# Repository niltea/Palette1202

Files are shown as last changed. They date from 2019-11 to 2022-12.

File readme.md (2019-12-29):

# Nilgiri12-02EC

English follows Japanese.

--------------------

Nilgiri12-02ECは、イラストレーターのための左手デバイスです。  
[Clip studio Paint](https://www.clipstudio.net) や、 [Adobe Photoshop](https://www.adobe.com/jp/products/photoshop.html)を使用した描画を快適に行うため設計されています。  
各種ショートカットを使用するためのキーを備えていることはもちろん、  
つまみを操作することで、ブラシサイズの変更やキャンバスの拡大・縮小等を快適に行うことができます。

コンパクトなサイズに設計されているため、持ち運んでの使用にも便利なだけでなく、  
据え置き環境で大型の液晶タブレットと一緒に使っても邪魔になりません。

また、オプションの電池キットを追加することで[BLE Micro Pro](https://yushakobo.jp/shop/ble-micro-pro/)にも対応するため、  
持ち運びの際でもケーブルが煩わしくありません。

Windows/Mac・Clip Studio / Photoshopの切替を行う事ができるため、  
PC・Macはもちろん、iPadでも同じ操作感で描画することができます。

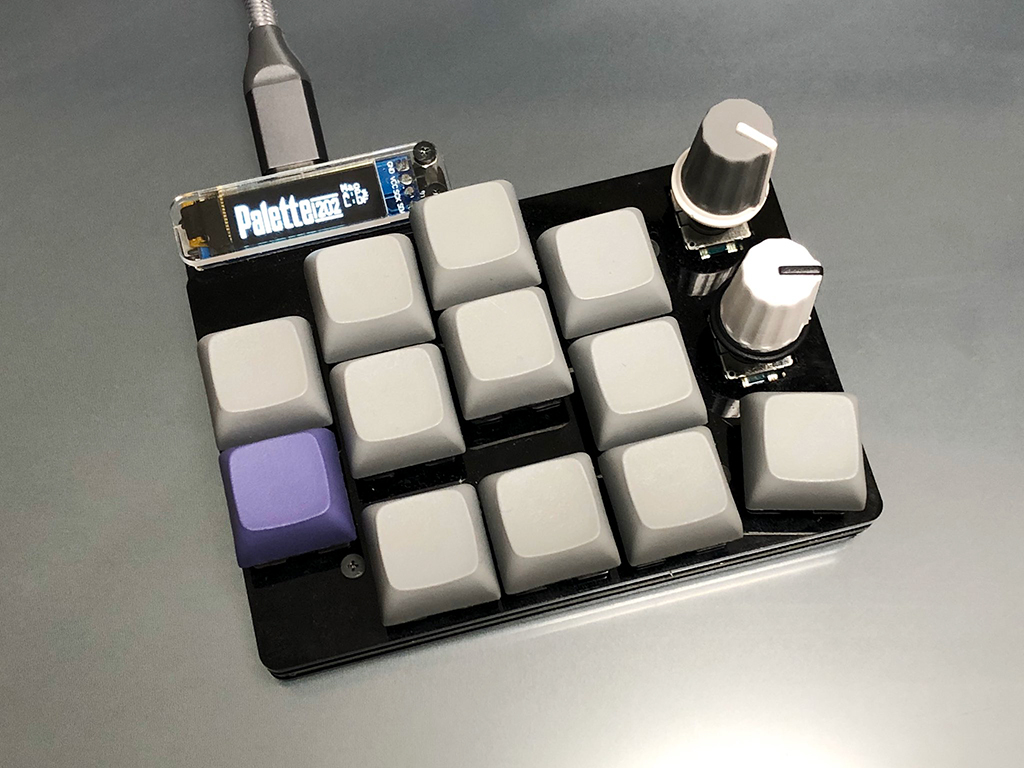
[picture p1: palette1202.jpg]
Palette1202


--------------------

Nilgiri12-02EC is a lefthand-devece for illustrators. 
Designed for comfotablly drawing on [Clip studio Paint](https://www.clipstudio.net) / [Adobe Photoshop](https://www.adobe.com/jp/products/photoshop.html).

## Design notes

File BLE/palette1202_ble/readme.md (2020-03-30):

# Palette1202-ble

Palette1202

A left hand device with rotary encoder, for artists.
firmware for BLE Micro Pro.

* Keyboard Maintainer: [niltea](https://github.com/niltea)
* Hardware Supported: Palette1202
* Hardware Availability: [Pixiv Booth](https://niltea.booth.pm/)
* [PCB & Case](https://github.com/niltea/Palette1202)

Make example for this keyboard (after setting up your build environment):

- default

		make palette1202-ble:default:nrfutil
        
- key check (for after build)

		make palette1202-ble:key-check:nrfutil

See the [build environment setup](https://docs.qmk.fm/#/getting_started_build_tools) and the [make instructions](https://docs.qmk.fm/#/getting_started_make_guide) for more information. Brand new to QMK? Start with our [Complete Newbs Guide](https://docs.qmk.fm/#/newbs).

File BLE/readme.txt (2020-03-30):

# firmware for Palette1202 BLE

BLE Micro Pro用のPalette1202ファームウェアです。

## フォルダ構成

### palette1202-ble/

QMK Firmware用のファイル一式です。
keyboards以下にコピーし、下記コマンドで書き込みを行ってください。  
```make palette1202-ble:default:nrfutil```

### config/

config / keymapファイルです。
ファームウェア書き込み後、BLE Micro Proをマスストレージデバイスとして接続し、転送してください。

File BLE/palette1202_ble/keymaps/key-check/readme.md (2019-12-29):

# The test-purpose keymap for niltea
組み立て後のテスト用keymapです。

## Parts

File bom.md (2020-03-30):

# Bills of materials

## Options

Option 1: direct mount ATmega32U4
Option 2: Use Pro Micro(uses 12pin Conthrough)
Option 3: Use BLE Micro Pro(uses 13pin Conthrough)

## List

| part ID | Description | Count | Remarks | Op1 | Op2 | Op3 |  color  |
|---|---|---| --- | :-: | :-: | :-: | :-----: |
| BT1-2 | Battery Holder(\*) | 2 | Keystone 504  | | |  v  | |
| C1 | Tantalum 1206 / 3216M | 1 | 10uF |  v  | | | |
| C2-3 | C 0603 / 1608M | 2 | 1uF |  v  | | | puprple |
| C4-5 | C 0603 / 1608M | 2 | 0.1uF |  v  | | |  green  |
| C6-7 | C 0603 / 1608M | 2 | 22pF |  v  | | | orange  |
| C10 | Tantalum 1206 / 3216M | 1 | 100uF | | |  v  | |
| U1 | Controller | 1 | ATmega32U4-AU |  v  | | | |
| U1 | Pro Micro | 1 | normal / BLE  | |  v  |  v  | |
| D1-14 | Diode | 14 | 1N4148W |  v  |  v  |  v  | |
| D20 | Shotkey Diode | 1 | MBR120 |  v  | | | |
| D31-32  | Shotkey Diode(\*) | 2 | MBR120 | | |  v  |
| R1-2 | R 0603 / 1608M | 2 | 5.1kΩ |  v  | | |
| R3-4 | R 0603 / 1608M | 2 | 22Ω |  v  | | |
| R5 | R 0603 / 1608M | 1 | 10kΩ |  v  | | |
| F1 | PTC 1206 / 3216M | 1 | 500mA |  v  | | |
| Y1 | Xtal 3225M 4pin | 1 | 16MHz |  v  | | |
| SW1-12  | Kailh Hotswap | 12 | MX / Choc |  v  |  v  |  v  |
| SW20 | Tactile Switch | 1 | 6mm x 3.5mm |  v  |  v  |  v  |
| SW21 | Slide Switch | 1 | SMD SPDT | | |  v  |
| EC1-2 | Rotary encoder | 2 | EC11E1834403  |  v  |  v  |  v  |
| knob | knob for encoder | 2 | 20mm max |  v  |  v  |  v  |
| J1 | USB Type-C | 1 | 16pin |  v  | | |
| J2 | USB Type-B Micro | 1 | micro,SMD |  v  | | |
| J3 | ISP Pin Header | 1 | 2x3pin | | | |
| J\* | Conthrough(\*) | 2 | 12 / 13pin | |  v  |  v  |
| OLED | | 1 | Optional | | | |

| vis     | M2 3mm                | 12    |               |  v  |  v  |  v  |
| spacer  | hirosugi M2x7mm       | 6     |               |  v  |  v  |  v  |

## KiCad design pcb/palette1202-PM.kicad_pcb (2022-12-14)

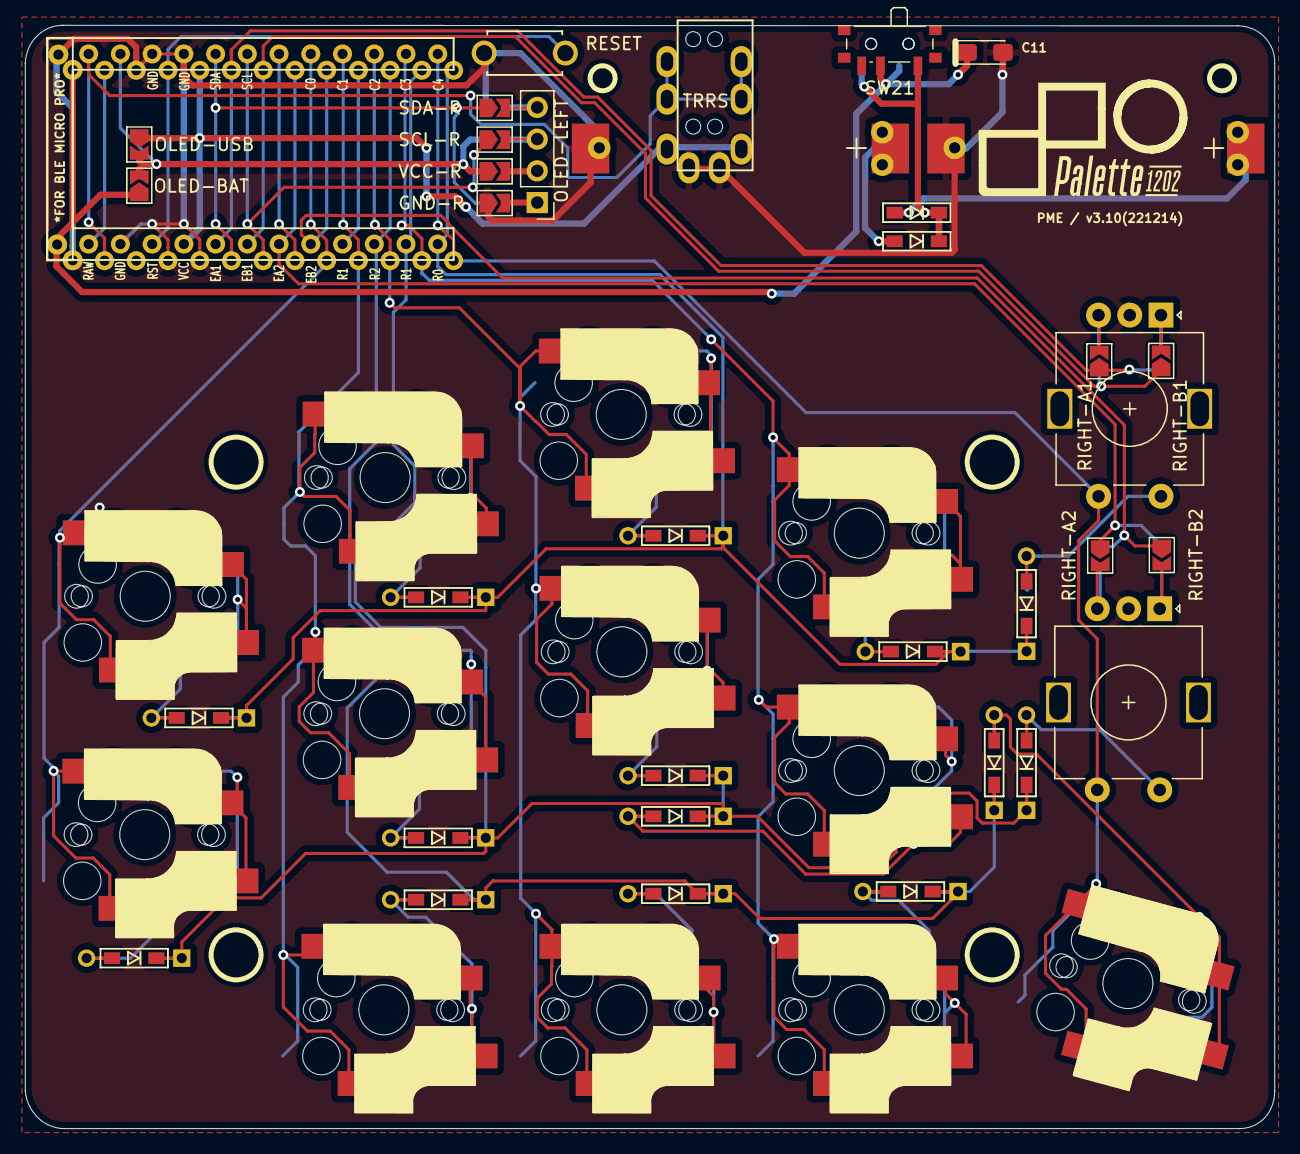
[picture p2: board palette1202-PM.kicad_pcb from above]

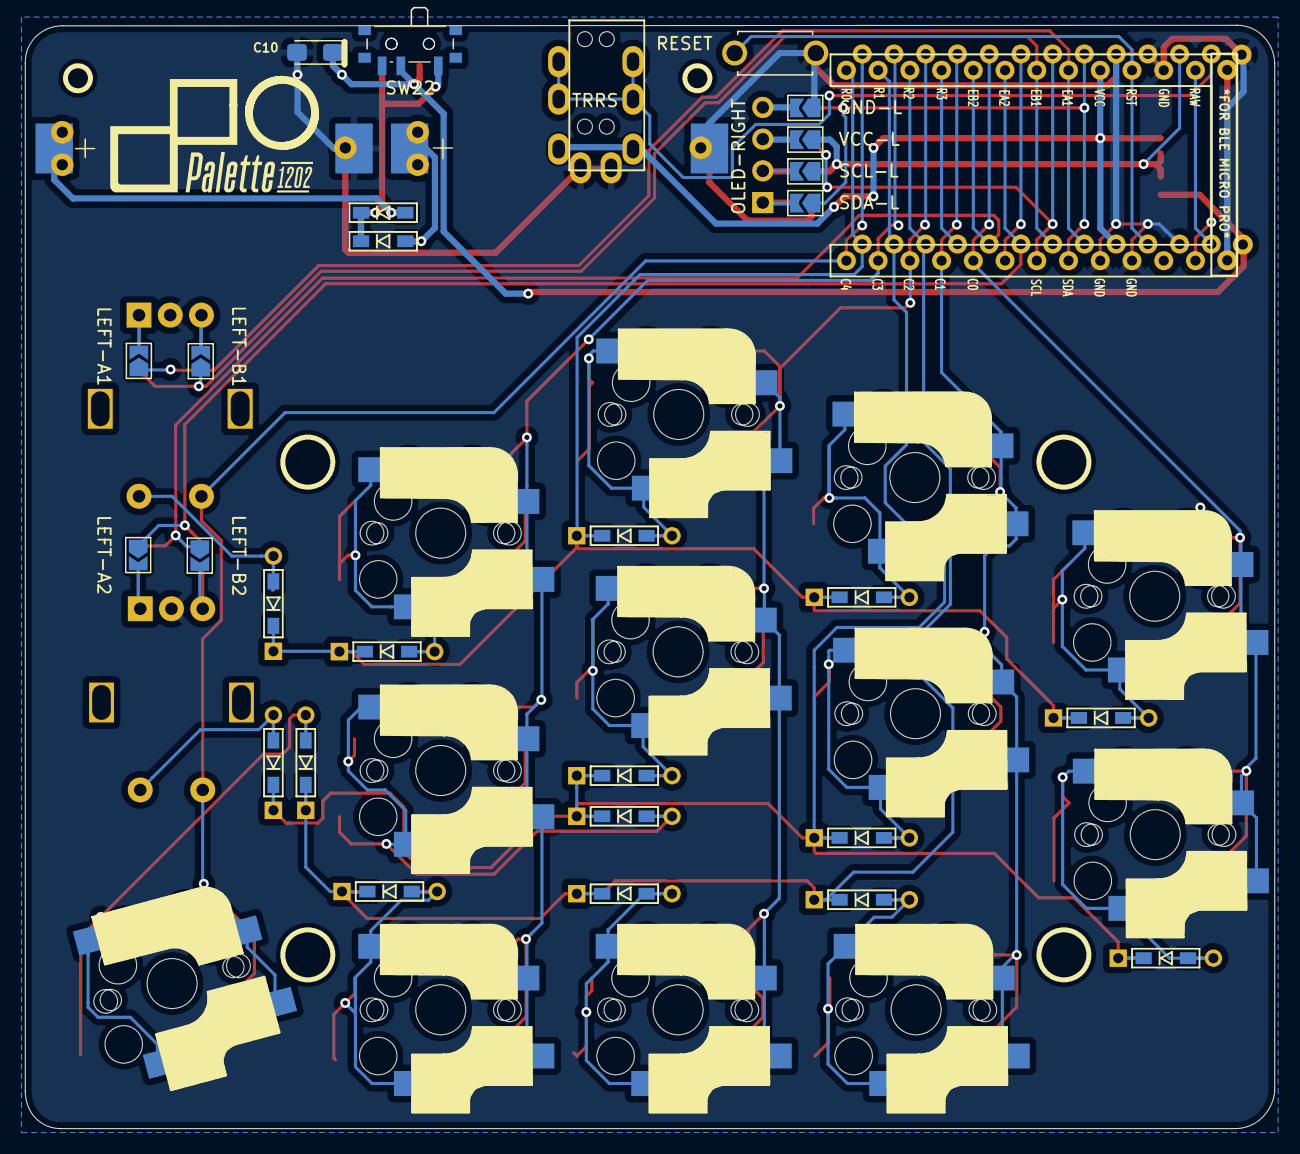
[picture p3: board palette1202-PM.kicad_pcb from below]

Board: 2 copper layers, 100.0 x 88.3 mm, 68 parts (26 on the bottom side), 45 nets.

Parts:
BT1, BT2: 3V; HU1632
C10, C11: 100u; CP_EIA-3216-10_Kemet-I_Pad1.58x1.35mm_HandSolder
D1, D2, D3, D4, D5, D6, D7, D8, D9, D10, D11, D12, D13, D14: 1N4148W; D3_TH_SMD
D30, D31: MBR120; D3_SMD
EC1, EC2: EC11E18244A5; RotaryEncoder_Alps_EC11E-Switch_Vertical_H20mm
GND-L: LEFT-GND; SolderJumper-2_P1.3mm_Open_TrianglePad1.0x1.5mm
GND-R: RIGHT-GND; SolderJumper-2_P1.3mm_Open_TrianglePad1.0x1.5mm
H1, H3: MountingHole; M2_vis
H5, H6, H7, H8: MountingHole; M2_spacer
J1: MJ-4PP-9
J10, J20: BAT+; Hole 0.8mm
J11, J21: BAT-; Hole 0.8mm
JP100: LEFT-A1; SolderJumper-2_P1.3mm_Open_TrianglePad1.0x1.5mm
JP101: LEFT-B1; SolderJumper-2_P1.3mm_Open_TrianglePad1.0x1.5mm
JP110: RIGHT-B1; SolderJumper-2_P1.3mm_Open_TrianglePad1.0x1.5mm
JP111: RIGHT-A1; SolderJumper-2_P1.3mm_Open_TrianglePad1.0x1.5mm
JP120: LEFT-A2; SolderJumper-2_P1.3mm_Open_TrianglePad1.0x1.5mm
JP121: LEFT-B2; SolderJumper-2_P1.3mm_Open_TrianglePad1.0x1.5mm
JP130: RIGHT-B2; SolderJumper-2_P1.3mm_Open_TrianglePad1.0x1.5mm
JP131: RIGHT-A2; SolderJumper-2_P1.3mm_Open_TrianglePad1.0x1.5mm
JP220: OLED-USB; SolderJumper-2_P1.3mm_Open_TrianglePad1.0x1.5mm
JP221: OLED-BAT; SolderJumper-2_P1.3mm_Open_TrianglePad1.0x1.5mm
OLED-LEFT: OLED; PinHeader_1x04_P2.54mm_Vertical
SCL-L: LEFT-SCL; SolderJumper-2_P1.3mm_Open_TrianglePad1.0x1.5mm
SCL-R: RIGHT-SCL; SolderJumper-2_P1.3mm_Open_TrianglePad1.0x1.5mm
SDA-L: LEFT-SDA; SolderJumper-2_P1.3mm_Open_TrianglePad1.0x1.5mm
SDA-R: RIGHT-SDA; SolderJumper-2_P1.3mm_Open_TrianglePad1.0x1.5mm
SW1, SW2, SW3, SW4, SW5, SW6, SW7, SW8, SW9, SW10, SW11, SW12: SW_PUSH; CherryMX_Choc_Hotswap
SW20: SW_RESET; ResetSW_1side
SW21, SW22: PWR; SW_SPDT_PCM12
U2: ProMicro; ProMicro_v2
VCC-L: LEFT-VCC; SolderJumper-2_P1.3mm_Open_TrianglePad1.0x1.5mm
VCC-R: RIGHT-VCC; SolderJumper-2_P1.3mm_Open_TrianglePad1.0x1.5mm

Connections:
Col0: SW1.1, SW2.1, U2.8 (5/C6)
Col1: SW3.1, SW4.1, SW5.1, U2.9 (6/D7)
Col2: SW6.1, SW7.1, SW8.1, U2.10 (7/E6)
Col3: SW9.1, SW10.1, SW11.1, U2.11 (8/B4)
Col4: EC1.S1, EC2.S1, SW12.1, U2.12 (9/B5)
DATA: J1.B, J1.C, U2.1 (TX0/D3)
GND: BT1.2 (-), BT2.2 (-), C10.2, C11.2, EC1.C, EC2.C, GND-L.1, GND-R.1, J1.A, J11.1, J21.1, SW20.1, U2.3 (GND), U2.4 (GND), U2.23 (GND)
LEFT: JP220.2 (B), JP221.2 (B), U2.2 (RX1/D2), VCC-L.1, VCC-R.1
unnamed: BT1.1 (+), D31.2 (A)
unnamed: BT2.1 (+), D30.2 (A)
unnamed: D1.2 (A), SW1.2
unnamed: D2.2 (A), SW2.2
unnamed: D3.2 (A), SW3.2
unnamed: D4.2 (A), SW4.2
unnamed: D5.2 (A), SW5.2
unnamed: D6.2 (A), SW6.2
unnamed: D7.2 (A), SW7.2
unnamed: D8.2 (A), SW8.2
unnamed: D9.2 (A), SW9.2
unnamed: D10.2 (A), SW10.2
unnamed: D11.2 (A), SW11.2
unnamed: D12.2 (A), SW12.2
unnamed: D13.2 (A), EC1.S2
unnamed: D14.2 (A), EC2.S2
unnamed: D30.1 (K), D31.1 (K), SW21.1 (A), SW22.1 (A)
unnamed: EC1.A, JP100.2, JP110.2
unnamed: EC1.B, JP101.2, JP111.2
unnamed: EC2.A, JP120.2, JP130.2
unnamed: EC2.B, JP121.2, JP131.2
unnamed: GND-R.2, OLED-LEFT.1, SDA-L.2
unnamed: OLED-LEFT.2, SCL-L.2, VCC-R.2
unnamed: OLED-LEFT.3, SCL-R.2, VCC-L.2
unnamed: GND-L.2, OLED-LEFT.4, SDA-R.2
RA1: JP100.1, JP111.1, U2.20 (F4/A3)
RA2: JP120.1, JP131.1, U2.18 (F6/A1)
RB1: JP101.1, JP110.1, U2.19 (F5/A2)
RB2: JP121.1, JP130.1, U2.17 (F7/A0)
RESET: SW20.2, U2.22 (RST)
Row0: D1.1 (K), D3.1 (K), D6.1 (K), D9.1 (K), D13.1 (K), U2.13 (B6/10)
Row1: D2.1 (K), D4.1 (K), D7.1 (K), D10.1 (K), D14.1 (K), U2.14 (B2/16)
Row2: D5.1 (K), D8.1 (K), D11.1 (K), D12.1 (K), U2.15 (B3/14)
SCL: SCL-L.1, SCL-R.1, U2.6 (3/D0/SCL)
SDA: SDA-L.1, SDA-R.1, U2.5 (2/D1/SDA)
VCC: J1.D, JP220.1 (A), U2.21 (VCC)
Vbat: C10.1, C11.1, J10.1, J20.1, JP221.1 (A), SW21.2 (B), SW22.2 (B)

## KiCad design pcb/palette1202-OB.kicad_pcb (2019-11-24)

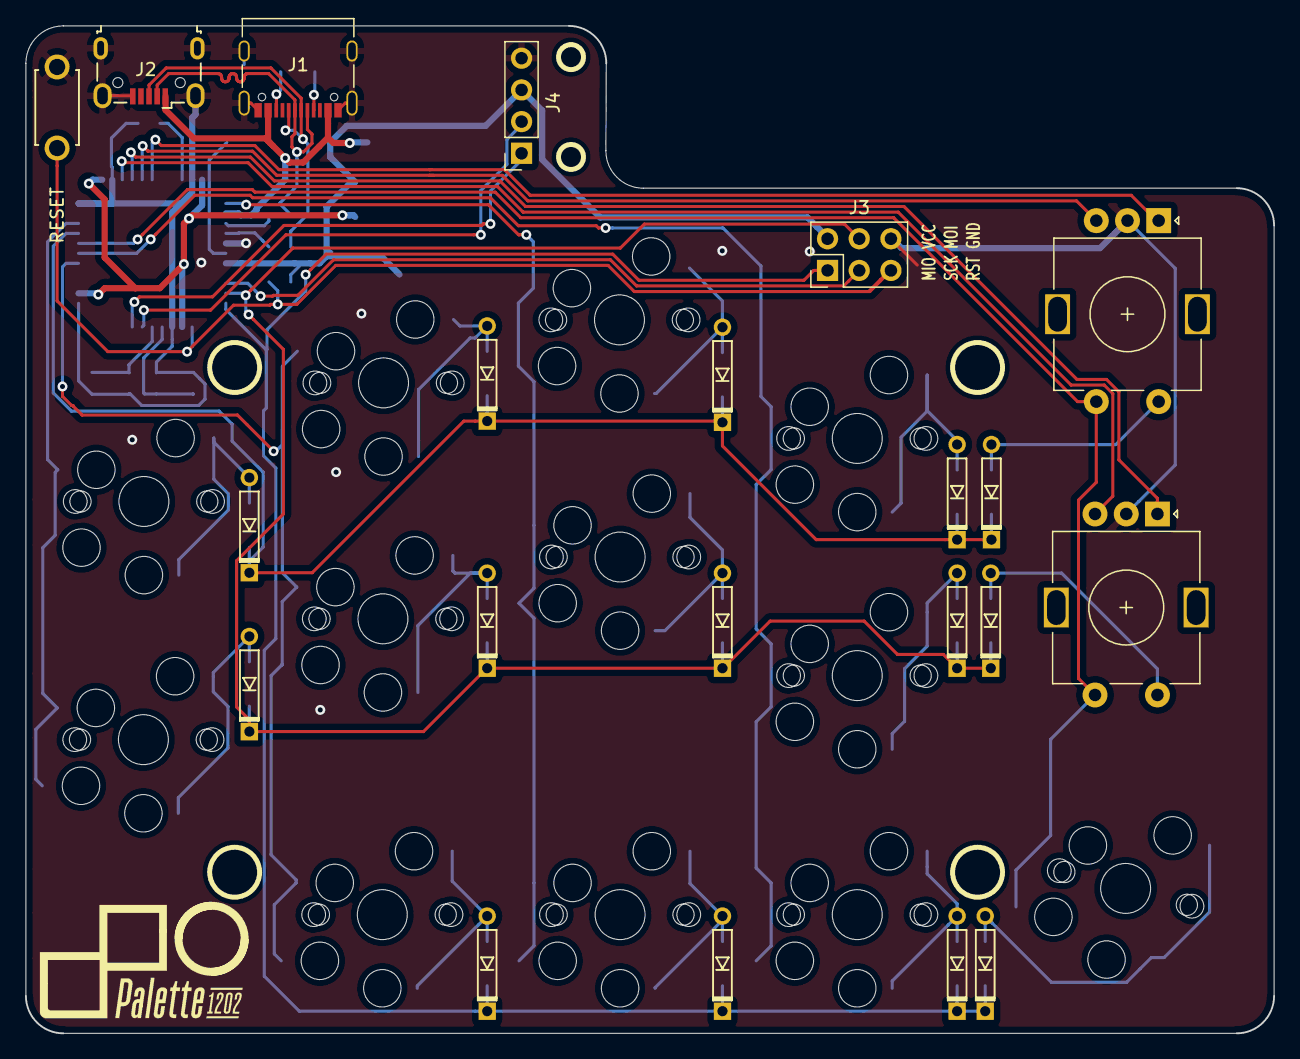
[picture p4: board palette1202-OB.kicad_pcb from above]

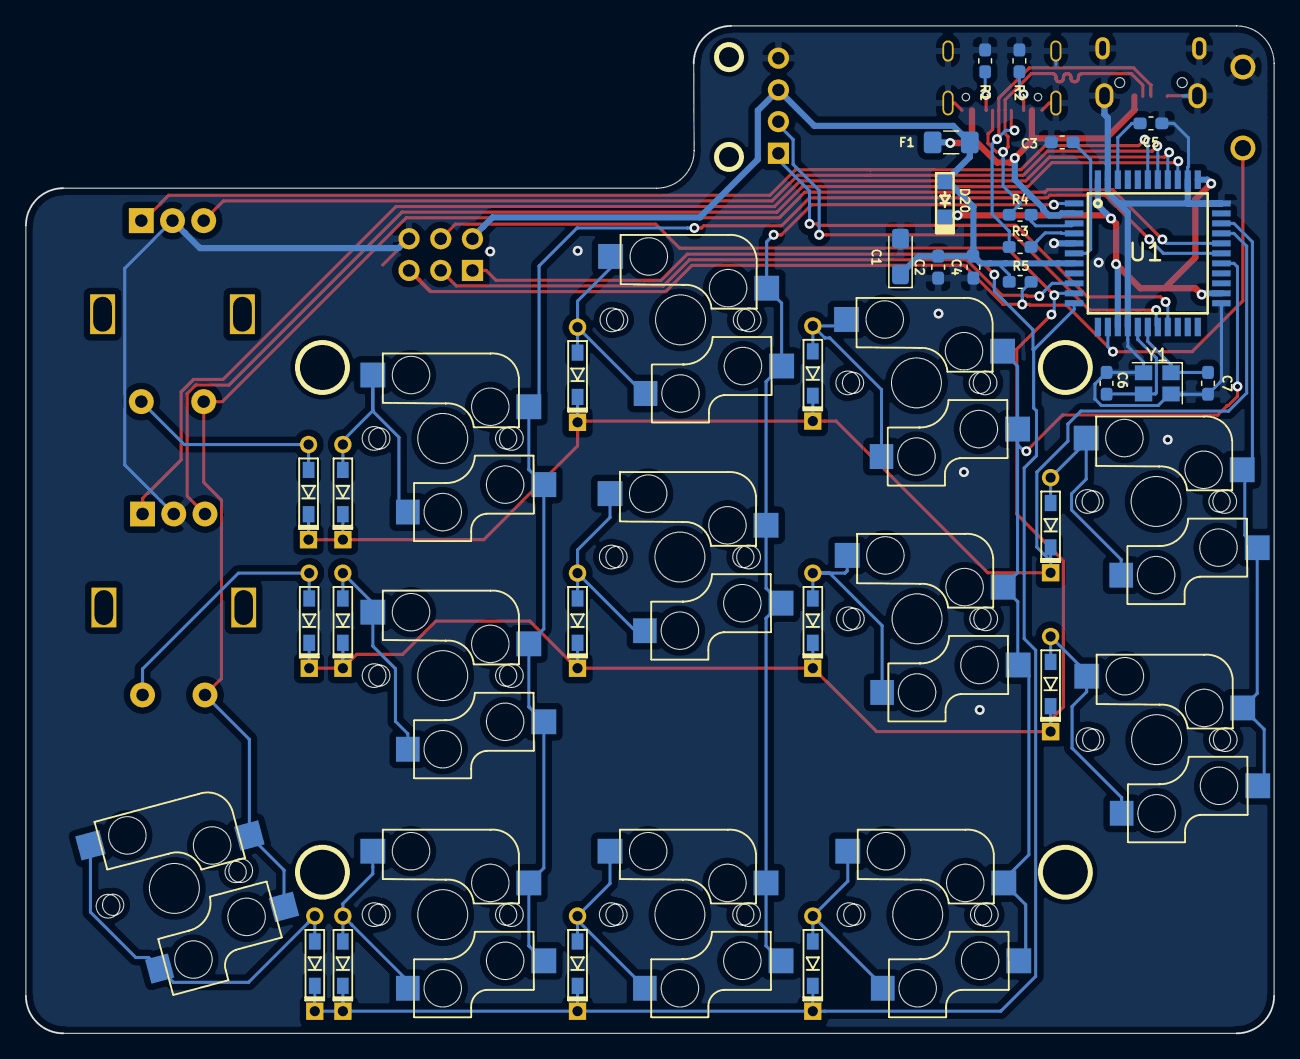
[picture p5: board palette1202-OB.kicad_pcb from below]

Board: 2 copper layers, 100.0 x 80.7 mm, 55 parts (30 on the bottom side), 44 nets.

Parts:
C1: 10u; CP_EIA-3216-10_Kemet-I_Pad1.58x1.35mm_HandSolder
C2, C3: 1u; C_0603_1608Metric_Pad1.05x0.95mm_HandSolder
C4, C5: 0.1u; C_0603_1608Metric_Pad1.05x0.95mm_HandSolder
C6, C7: 22p; C_0603_1608Metric_Pad1.05x0.95mm_HandSolder
D1, D2, D3, D4, D5, D6, D7, D8, D9, D10, D11, D12, D13, D14: 1N4148W; D3_TH_SMD
D20: MBR120; D_SOD123F
EC1, EC2: EC11E18244A5; RotaryEncoder_Alps_EC11E-Switch_Vertical_H20mm
F1: 500mA; Fuse_1206_3216Metric_Pad1.42x1.75mm_HandSolder
H1, H3: MountingHole; M2_vis
H5, H6, H7, H8: MountingHole; M2_spacer
J1: USB-C; USB_C_Receptacle_Palconn_UTC16-G
J2: USB_B_Micro; USB_Micro-B_Wuerth_629105150521
J3: ISP; PinHeader_2x03_P2.54mm_Vertical
J4: OLED; PinSocket_1x04_P2.54mm_Vertical
R1, R2: 5.1k; R_0603_1608Metric_Pad1.05x0.95mm_HandSolder
R3, R4: 22; R_0603_1608Metric_Pad1.05x0.95mm_HandSolder
R5: 10k; R_0603_1608Metric_Pad1.05x0.95mm_HandSolder
SW1, SW2, SW3, SW4, SW5, SW6, SW7, SW8, SW9, SW10, SW11, SW12: SW_PUSH; CherryMX_Choc_Hotswap-1Side
SW20: SW_RESET; ResetSW_1side
U1: ATmega32U4-AU; ATMEGA32U4-AU
Y1: 16MHz; Crystal_SMD_3225-4Pin_3.2x2.5mm

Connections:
Col0: SW1.1, SW2.1, U1.31
Col1: SW3.1, SW4.1, SW5.1, U1.27
Col2: SW6.1, SW7.1, SW8.1, U1.1
Col3: SW9.1, SW10.1, SW11.1, U1.28
Col4: EC1.S1, EC2.S1, SW12.1, U1.29
D+: J1.A6, J1.B6, J2.3, R3.2
D-: J1.A7, J1.B7, J2.2, R4.2
GND: C1.2, C2.2, C3.2, C4.2, C5.2, C6.2, C7.1, EC1.C, EC2.C, J1.A1, J1.A12, J1.B1, J1.B12, J1.S1, J2.5, J2.6, J3.6, J4.4, R1.1, R2.1, SW20.1, U1.5, U1.15, U1.23, U1.33, U1.35, U1.43, Y1.2, Y1.4
MISO: D5.1, D8.1, D11.1, D12.1, J3.1, U1.11
MOSI: D2.1, D4.1, D7.1, D10.1, D14.1, J3.4, U1.10
unnamed: C3.1, U1.6
unnamed: C5.1, U1.42
unnamed: C6.1, U1.16, Y1.3
unnamed: C7.2, U1.17, Y1.1
unnamed: D1.2, SW1.2
unnamed: D2.2, SW2.2
unnamed: D3.2, SW3.2
unnamed: D4.2, SW4.2
unnamed: D5.2, SW5.2
unnamed: D6.2, SW6.2
unnamed: D7.2, SW7.2
unnamed: D8.2, SW8.2
unnamed: D9.2, SW9.2
unnamed: D10.2, SW10.2
unnamed: D11.2, SW11.2
unnamed: D12.2, SW12.2
unnamed: D13.2, EC1.S2
unnamed: D14.2, EC2.S2
unnamed: D20.1, U1.14, U1.24, U1.34, U1.44
unnamed: J1.A5, R1.2
unnamed: J1.B5, R2.2
unnamed: R3.1, U1.4
unnamed: R4.1, U1.3
RA1: EC1.A, U1.39
RA2: EC2.A, U1.37
RB1: EC1.B, U1.38
RB2: EC2.B, U1.36
RESET: J3.5, R5.2, SW20.2, U1.13
Row0: D1.1, D3.1, D6.1, D9.1, D13.1, U1.30
SCK: J3.3, U1.9
SCL: J4.2, U1.18
SDA: J4.1, U1.19
VBUS: F1.2, J1.A4, J1.A9, J1.B4, J1.B9, J2.1, U1.2
VCC: C1.1, C2.1, C4.1, D20.2, F1.1, J3.2, J4.3, R5.1, U1.7

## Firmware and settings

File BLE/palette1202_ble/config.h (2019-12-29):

/*
Copyright 2019 niltea

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
You should have received a copy of the GNU General Public License
along with this program.  If not, see <http://www.gnu.org/licenses/>.
*/

#pragma once

#ifndef __ASSEMBLER__
#include "config_common.h"
#include "apidef.h"

/* USB Device descriptor parameter */
#define VENDOR_ID    0xFEED
#define PRODUCT_ID   0x0000
#define DEVICE_VER   0x0001
#define MANUFACTURER niltea
#define PRODUCT      Palette1202
#define DESCRIPTION  A left hand device with rotary encoder

#define BMP_BOOTPIN_AS_RESET

#define TAPPING_TERM_PER_KEY
#define PERMISSIVE_HOLD
#define PREVENT_STUCK_MODIFIERS
#define TAPPING_TERM 200

/* key matrix size */
#define MATRIX_ROWS_DEFAULT 3
#define MATRIX_COLS_DEFAULT 5
#define THIS_DEVICE_ROWS 3
#define THIS_DEVICE_COLS 5
#define IS_LEFT_HAND  true
#define BMP_DEFAULT_MODE SINGLE
#define ENABLE_STARTUP_ADV_NOLIST

#define MATRIX_ROW_PINS { 13, 14, 15 }
#define MATRIX_COL_PINS { 8, 9, 10, 11, 12 }
#define MATRIX_LAYOUT {\
    1,   2,  3,  4,  5,  0,\
    6,   7,  8,  9,  10, 0,\
    255, 11, 12, 13, 14, 15}

#define KEYMAP_PRIOR_LOCALE 0
#define KEYMAP_ASCII 0

/* COL2ROW, ROW2COL*/
#define DIODE_DIRECTION COL2ROW

/* Rotary encoder define*/
#define ENCODERS_PAD_A { 20, 18 }
#define ENCODERS_PAD_B { 19, 17 }
#define ENCODER_RESOLUTION  4
#define MATRIX_SCAN_TIME_MS 2

#define KEYMAP_PRIOR_LOCALE 0
#define KEYMAP_ASCII 0

#define RGBLIGHT_SPLIT
#define RGB_DI_PIN 255
#ifdef RGB_DI_PIN
  #define RGBLED_NUM_DEFAULT 128
  #define RGBLIGHT_HUE_STEP 8
  #define RGBLIGHT_SAT_STEP 8
  #define RGBLIGHT_VAL_STEP 8
  #define RGBLIGHT_LIMIT_VAL 255 /* The maximum brightness level */
  #define RGBLIGHT_SLEEP  /* If defined, the RGB lighting will be switched off when the host goes to sleep */
/*== all animations enable ==*/
  #define RGBLIGHT_ANIMATIONS
/*== or choose animations ==*/
  #define RGBLIGHT_EFFECT_BREATHING
  #define RGBLIGHT_EFFECT_RAINBOW_MOOD
  #define RGBLIGHT_EFFECT_RAINBOW_SWIRL
  #define RGBLIGHT_EFFECT_SNAKE
  #define RGBLIGHT_EFFECT_KNIGHT
  #define RGBLIGHT_EFFECT_CHRISTMAS
  #define RGBLIGHT_EFFECT_STATIC_GRADIENT
  #define RGBLIGHT_EFFECT_RGB_TEST
  #define RGBLIGHT_EFFECT_ALTERNATING
/*== customize breathing effect ==*/
  /*==== (DEFAULT) use fixed table instead of exp() and sin() ====*/
  #define RGBLIGHT_BREATHE_TABLE_SIZE 256      // 256(default) or 128 or 64
  /*==== use exp() and sin() ====*/
  #define RGBLIGHT_EFFECT_BREATHE_CENTER 1.85  // 1 to 2.7
  #define RGBLIGHT_EFFECT_BREATHE_MAX    255   // 0 to 255
#endif

/* Debounce reduces chatter (unintended double-presses) - set 0 if debouncing is not needed */
#define DEBOUNCE 1

#define DEBUG_ACTION

/* Mechanical locking support. Use KC_LCAP, KC_LNUM or KC_LSCR instead in keymap */
#define LOCKING_SUPPORT_ENABLE
/* Locking resynchronize hack */
#define LOCKING_RESYNC_ENABLE

/* Register custom font file */
#ifdef OLED_DRIVER_ENABLE
  #define OLED_FONT_H "./lib/glcdfont.c"
#endif
#endif /*__ASSEMBLER__*/

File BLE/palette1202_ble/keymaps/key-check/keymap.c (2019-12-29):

	/* Copyright 2019 niltea
 *
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
 * You should have received a copy of the GNU General Public License
 * along with this program.  If not, see <http://www.gnu.org/licenses/>.
 */
#include QMK_KEYBOARD_H
#ifdef OLED_DRIVER_ENABLE
  #include <string.h>
  #include "lib/oled_helper.h"
#endif

// Defines the keycodes used by our macros in process_record_user
enum custom_keycodes {
    KEY_01 = SAFE_RANGE,
    KEY_02,
    KEY_03,
    KEY_04,
    KEY_05,
    KEY_06,
    KEY_07,
    KEY_08,
    KEY_09,
    KEY_10,
    KEY_11,
    KEY_12,
    KEY_13,
    KEY_14
};

const uint16_t PROGMEM keymaps[][MATRIX_ROWS][MATRIX_COLS] = {
    [0] = LAYOUT(
        KEY_01, KEY_02, KEY_03, KEY_04, KEY_05,
        KEY_06, KEY_07, KEY_08, KEY_09, KEY_10,
                KEY_11, KEY_12, KEY_13, KEY_14
    ),
};

bool process_record_user(uint16_t keycode, keyrecord_t *record) {
    switch (keycode) {
        case KEY_01:
            if (record->event.pressed) {
                SEND_STRING("R1C1");
            }
            break;
        case KEY_02:
            if (record->event.pressed) {
                SEND_STRING("R1C2");
            }
            break;
        case KEY_03:
            if (record->event.pressed) {
                SEND_STRING("R1C3");
            }
            break;
        case KEY_04:
            if (record->event.pressed) {
                SEND_STRING("R1C4");
            }
            break;
        case KEY_05:
            if (record->event.pressed) {
                SEND_STRING("ENCODER-UPPER:Button");
            }
            break;

        case KEY_06:
            if (record->event.pressed) {
                SEND_STRING("R2C1");
            }
            break;
        case KEY_07:
            if (record->event.pressed) {
                SEND_STRING("R2C2");
            }
            break;
        case KEY_08:
            if (record->event.pressed) {
                SEND_STRING("R2C3");
            }
            break;

        case KEY_09:
            if (record->event.pressed) {
                SEND_STRING("R2C4");
            }
            break;
        case KEY_10:
            if (record->event.pressed) {
                SEND_STRING("ENCODER-LOWER:Button");
            }
            break;
        case KEY_11:
            if (record->event.pressed) {
                SEND_STRING("R3C1");
            }
            break;
        case KEY_12:
            if (record->event.pressed) {
                SEND_STRING("R3C2");
            }
            break;
        case KEY_13:
            if (record->event.pressed) {
                SEND_STRING("R3C3");
            }
            break;
        case KEY_14:
            if (record->event.pressed) {
                SEND_STRING("R3C4");
            }
            break;
    }
    return true;
}

void encoder_update_user(uint8_t index, bool clockwise) {
  if (index == 0) { /* the upper encoder */
    if (clockwise) {
      SEND_STRING("ENCODER-UPPER:CW");
    } else {
      SEND_STRING("ENCODER-UPPER:CCW");
    }
  } else if (index == 1) { /* the lower encoder */
    if (clockwise) {
      SEND_STRING("ENCODER-LOWER:CW");
    } else {
      SEND_STRING("ENCODER-LOWER:CCW");
    }
  }
}

// OLED Display
#ifdef OLED_DRIVER_ENABLE
void oled_task_user(void) {
  render_row(0, "TEST");
  render_row(1, "test");
  render_row(2, "TEST");
  render_row(3, "test");
}
#endif // #ifdef OLED_DRIVER_ENABLE

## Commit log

2019-10-24 addede BOM(WIP)
2019-10-25 merged onboard type / added footprints
    [nilgiri.kicad_pcb, nilgiri.sch]
2019-10-26 combined Onboard type and Pro Micro type
    [nilgiri.kicad_pcb, nilgiri.sch]
2019-10-29 全体調整
    [nilgiri-B_Cu.gbl, nilgiri-B_Mask.gbs, nilgiri-B_SilkS.gbo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]
2019-10-29 gerberファイル再出力
    [nilgiri-B_Cu.gbl, nilgiri-B_Mask.gbs, nilgiri-B_SilkS.gbo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]
2019-11-03 moved PCBs to their dir
    [nilgiri-B_Cu.gbl, nilgiri-B_Mask.gbs, nilgiri-B_SilkS.gbo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]
2019-11-15 added key footprints
2019-11-24 rm hot-swap ver
    [nilgiri_hotswap.kicad_pcb, nilgiri_hotswap.sch]
2019-11-24 updated normal PCB
    [nilgiri.kicad_pcb, nilgiri.sch, palette1202-PM.kicad_pcb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]
2019-11-24 added onboard PCB
    [palette1202-OB.kicad_pcb, palette1202-OB.sch]
2019-11-24 revised footprint
2019-11-24 fixed front panel
    [nilgiri_front.kicad_pcb]
2019-11-24 renamed files
    [palette1202-COM_front.kicad_pcb, palette1202-COM_front.sch, palette1202-PM-back.kicad_pcb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]
2019-11-24 added back plate(OB)
    [palette1202-OB-back.kicad_pcb, palette1202-OB-back.sch]
2019-11-24 revised annotation, BOM, etc.
    [palette1202-OB.kicad_pcb, palette1202-OB.sch, palette1202-PM.kicad_pcb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]
2019-11-24 output gerber
    [nilgiri-B_Cu.gbl, nilgiri-B_Mask.gbs, nilgiri-B_SilkS.gbo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]
2019-12-29 added PCB Exported SVG
2020-03-29 updated main board
    [palette1202-PM.kicad_pcb, palette1202-PM.sch]
2020-03-29 renamed front
    [palette1202-front.kicad_pcb, palette1202-front.sch]
2020-03-29 updated front panel
    [palette1202-front.kicad_pcb]
2020-03-29 updated back panel
    [palette1202-PM-back.kicad_pcb, palette1202-PM-back.sch]
2020-03-29 export gerber
    [palette1202-COM_front-B_Mask.gbs, palette1202-COM_front-B_SilkS.gbo, palette1202-COM_front-F_Mask.gts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]
2020-04-15 fix BLE firm for iOS
    [keymap.c]
2022-12-01 added connecter for split layout(testing)
    [palette1202-PM-B_Cu.gbl, palette1202-PM-B_Mask.gbs, palette1202-PM-B_SilkS.gbo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]
2022-12-14 minor fix, etc.
    [palette1202-PM-B_Cu.gbl, palette1202-PM-B_Mask.gbs, palette1202-PM-B_Silkscreen.gbo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]

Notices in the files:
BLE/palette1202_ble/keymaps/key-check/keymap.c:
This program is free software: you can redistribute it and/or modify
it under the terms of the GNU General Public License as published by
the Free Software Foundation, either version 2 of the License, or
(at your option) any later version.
